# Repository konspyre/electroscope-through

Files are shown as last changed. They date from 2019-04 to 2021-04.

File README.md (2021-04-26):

# electroscope (through-hole edition)

This is a similar board to the [surface mount electroscope](https://github.com/davidk/electroscope) but is easier (or harder, depending on your manufacturing viewpoint) to assemble and source parts for.

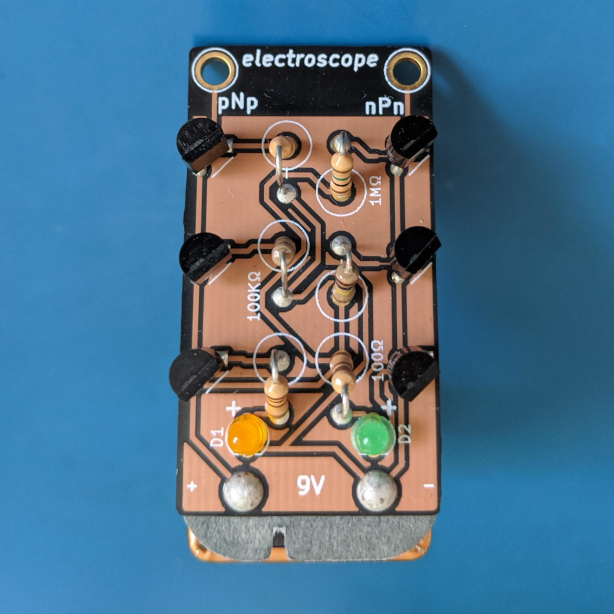
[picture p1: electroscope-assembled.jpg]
assembled electroscope board with a copper poour


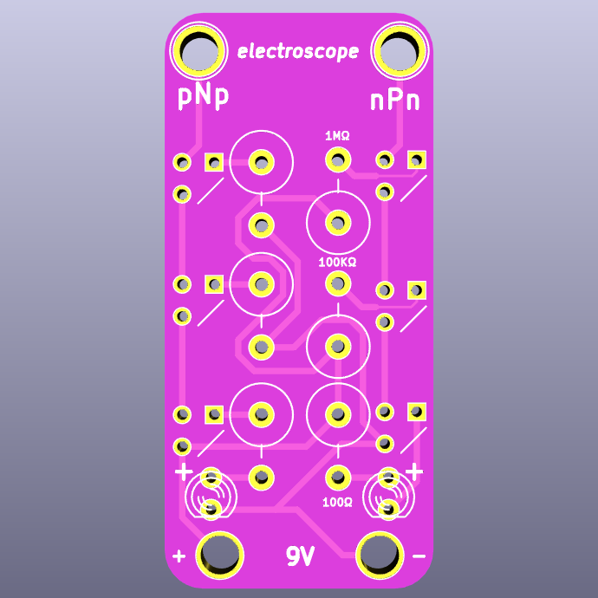
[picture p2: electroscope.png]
kicad's render of the electroscope board




### Bill of Materials

This BOM specifies the amount needed for _one_ board. Parts have been translated from their surface mount equivalents.

| Quantity | Description | Digikey Part Number | Board Placement |
| --- | --- | --- | --- |
| 3 | 2N3906 | [2N3906D26ZCT-ND](https://www.digikey.com/products/en?keywords=2N3906D26ZCT-ND) | Left (label: PNP) |
| 3 	 | 2N3904	 | [2N3904FS-ND](https://www.digikey.com/products/en?keywords=2N3904FS-ND) | Right (label: NPN) |
| 2 | 100 ohm resistor | [100QBK-ND](https://www.digikey.com/product-detail/en/CFR-25JB-52-100R/100QBK-ND/246) | Bottom (label: 100 ohm) |
| 2 | 100k ohm resistor | [100KQBK-ND](https://www.digikey.com/products/en?keywords=100kQBK-ND) | Middle (label: 100k ohm) |
| 2	 | 1M ohm resistor | [1.0MQBK-ND](https://www.digikey.com/product-detail/en/yageo/CFR-25JB-52-1M/1.0MQBK-ND/99) | Top (label: 1M ohm) |

### Battery connector

| Quantity | Description | Digikey Part Number | Board Placement |
| --- | --- | --- | --- |
| 1 | 9v through-hole battery snap - long | [36-968-ND](https://www.digikey.com/product-detail/en/keystone-electronics/968/36-968-ND/151577) | 9V terminals (verify before soldering by attaching to a 9V battery -- reworking afterwards is difficult without specialized tools/materials) |

or

| Quantity | Description | Digikey Part Number | Board Placement |
| --- | --- | --- | --- |
| 1 | 9v through-hole battery snap - short | [36-967-ND](https://www.digikey.com/product-detail/en/keystone-electronics/967/36-967-ND/2745660) |  9V terminals (verify before soldering by attaching to a 9V battery -- reworking afterwards is difficult without specialized tools/materials) |

#### LEDs

| Quantity | Description | Digikey Part Number | Board Placement |
| --- | --- | --- | --- |
| 2 | 3mm LEDs | (Red: [160-1704-ND](http://www.digikey.com/product-search/en?vendor=0&keywords=160-1704-ND) / Green: [160-1958-ND](http://www.digikey.com/product-search/en?vendor=0&keywords=160-1958-ND) | Bottom (verify orientation before soldering!) |

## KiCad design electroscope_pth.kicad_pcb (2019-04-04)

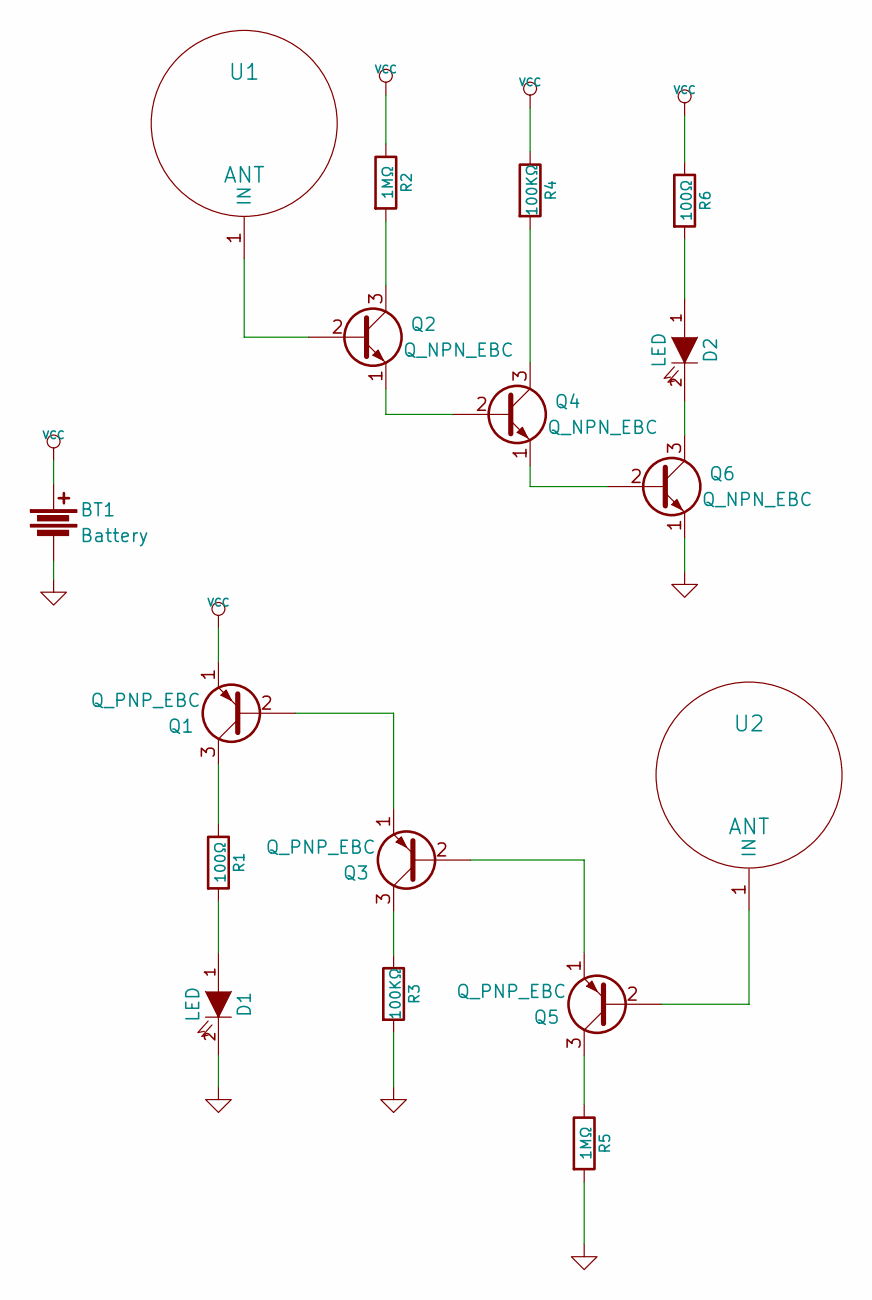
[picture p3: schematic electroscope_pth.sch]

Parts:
BT1: Battery
D1, D2: LED
Q1, Q3, Q5: Q_PNP_EBC
Q2, Q4, Q6: Q_NPN_EBC
R1, R6: 100Ω
R2, R5: 1MΩ
R3, R4: 100KΩ
U1, U2: ANT

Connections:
GND: BT1.2, D1.2 (K), Q6.1 (E), R3.2, R5.2
unnamed: D1.1 (A), R1.2
unnamed: D2.1 (A), R6.2
unnamed: D2.2 (K), Q6.3 (C)
unnamed: Q1.2 (B), Q3.1 (E)
unnamed: Q1.3 (C), R1.1
unnamed: Q2.1 (E), Q4.2 (B)
unnamed: Q2.2 (B), U1.1
unnamed: Q2.3 (C), R2.2
unnamed: Q3.2 (B), Q5.1 (E)
unnamed: Q3.3 (C), R3.1
unnamed: Q4.1 (E), Q6.2 (B)
unnamed: Q4.3 (C), R4.2
unnamed: Q5.2 (B), U2.1
unnamed: Q5.3 (C), R5.1
VCC: BT1.1, Q1.1 (E), R2.1, R4.1, R6.1

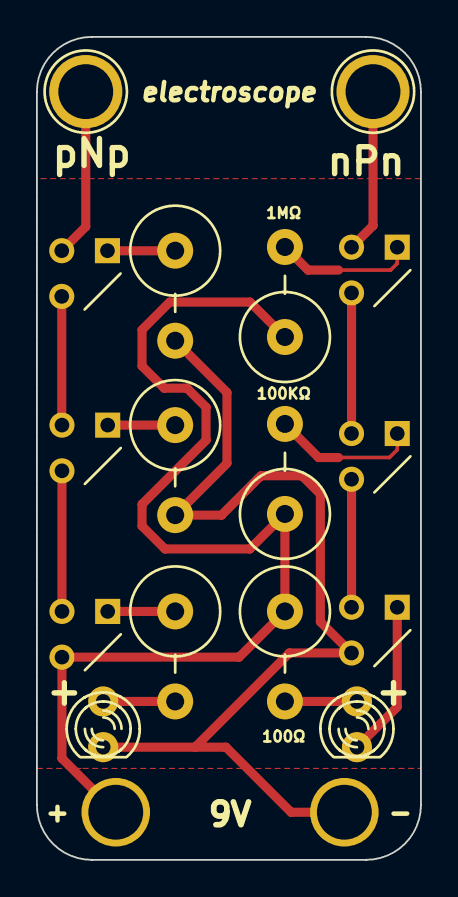
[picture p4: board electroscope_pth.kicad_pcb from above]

Board: 2 copper layers, 21.3 x 45.7 mm, 17 parts (0 on the bottom side), 16 nets.

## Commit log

2015-09-08 Add libs, and schematic
    [electroscope_pth.sch]
2015-09-09 Add pcb backup to .gitignore
2015-09-09 General placement down
    [electroscope_pth.sch]
2015-09-09 Add untracked files
    [electroscope_pth.kicad_pcb]
2015-09-09 Ready to mill
    [electroscope_pth-B_Cu.gbr, electroscope_pth-B_Mask.gbr, electroscope_pth-B_SilkS.gbr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]
2015-09-09 Add isolated plane @ bottom 3/4ths or so of board
    [electroscope_pth.kicad_pcb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]
2019-03-13 Re-route PCB with centered dimensions and rework footprint silkscreens
    [electroscope_pth.kicad_pcb]
2019-03-14 Add re-routing
    [electroscope_pth.kicad_pcb]
2019-03-14 Route to the edges of the board
    [electroscope_pth.kicad_pcb]
2019-03-14 Add a more up-to-date gitignore for KiCad
2019-03-14 Add updated electroscope schematic
    [electroscope_pth.sch]
2019-03-14 Add new gerbers based on board re-route
    [electroscope_pth-B.Cu.gbr, electroscope_pth-B.Mask.gbr, electroscope_pth-B.SilkS.gbr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]
2019-03-15 More rounding and compaction
    [electroscope_pth.kicad_pcb]
2019-03-16 electroscope: Remove flood fill overlap
    [electroscope_pth.kicad_pcb]
2019-03-16 electroscope: silkscreen improvements
    [electroscope_pth.kicad_pcb]
2019-03-21 Add current electroscope
2019-04-04 Center 1M silk
    [electroscope_pth.kicad_pcb]
2019-09-07 README: Change battery connector
2021-04-26 Add picture of assembled electroscope
